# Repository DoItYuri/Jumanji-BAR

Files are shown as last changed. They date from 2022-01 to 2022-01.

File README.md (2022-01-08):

# Jumanji-BAR
шкафчик-бар, дверцы в стиле Джуманджи, с озвучкой (бой барабанов) и подсветкой

> [!WARNING]
> проект только начинается, и планируется завершить его к Маю 2022...

# Задумка
Сделать шкаф-бар (для алкоголя) стилизованного под Джуманджи.

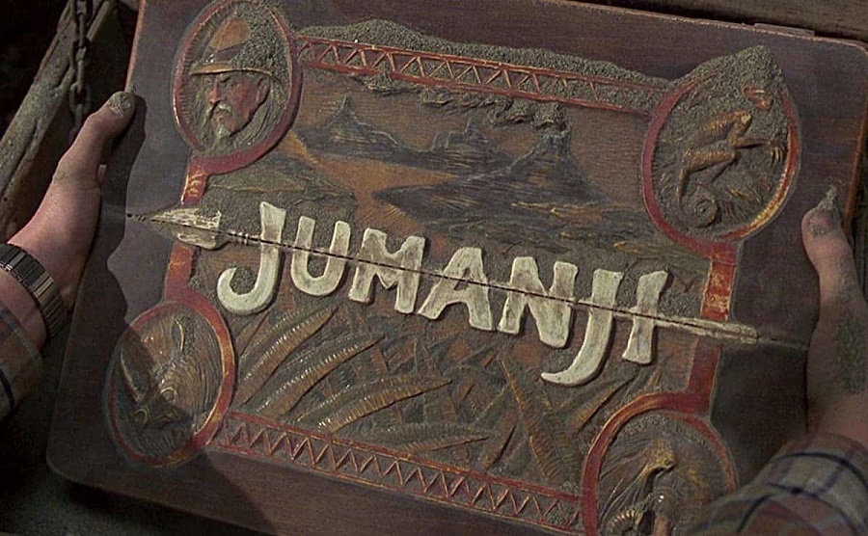
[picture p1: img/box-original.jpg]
original view


Кроме внешнего вида, будет музыкальное сопровождения, как в фильме.<br/>
При появлении рядом кого-либо, включается барабанный бой с постепенным нарастанием громкости<br/>
При приближении кого либо (к шкафу) - громкость и барабанный бой меняются до максимально громкого<br/>
При прикосновении к шкафчику (ручки-выемки сбоку) бой прекращается.<br/>
При открытии, включается подсветка в шкафчике (и можно включить саундтрек Jumanji)<br/>
При закрытии и отходе от шкафа, барабаны негромко и недолго снова играют.<br/>

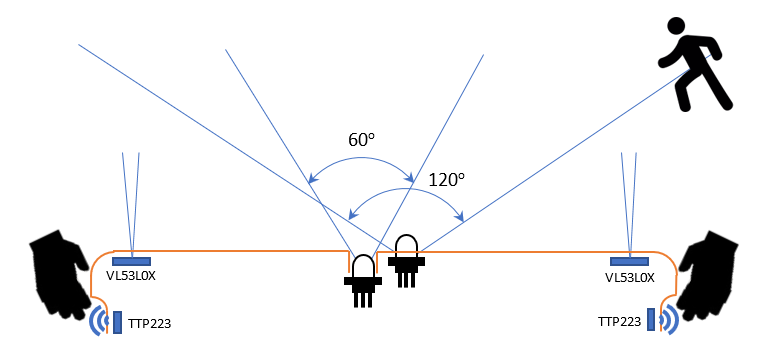
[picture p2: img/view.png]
view


# План действий
- барабанный бой можной найти в фильме, на 23-24 минутах, где дети поднимаются по лестнице и находят коробку.
Барабанный бой поделен на 4 части по интенсивности звучания:
    - далекий (который дети слышат его внизу)
    - средний (когда дети входят в комнату)
    - близкий (когда дети обнаружили коробку)
    - завершение (последние пара ударов в барабан для грациозного завершения, как в фильме)
- шкаф будет изготовлен из дерева, с фрезерованием на станке с ЧПУ. Нижняя дверца должна откидываться на 90 градусов и образовывать полку. Верхняя дверца должна синхронно подниматься кверху на 90 градусов. (Шкафчик будет больше и глубже чем коробка в фильме)
- музыкальная и интерактивная часть планируется с использованием Arduino Nano, прошивка которой и будет здесь представлена.

[3D model для фасада](https://www.thingiverse.com/thing:2410181)

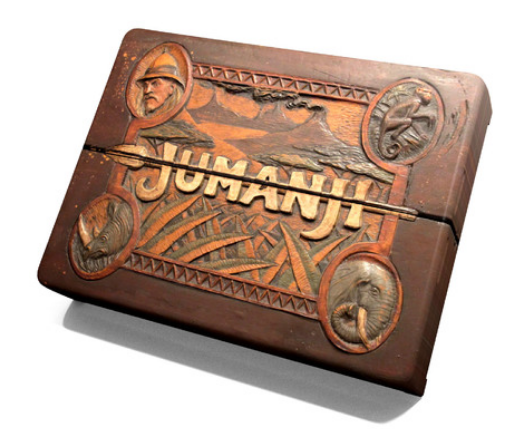
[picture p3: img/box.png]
3D model


# Компоненты
- Arduino Nano
- DFPlayer mini
- PIR (mini) sensor (x2)
- Distance sensor VL53L0X
- Touch sensor TTP223 (x2)
- Speaker 3W
- WS2812 strip (подсветка внутри, опционально)
- DC 5V 3A

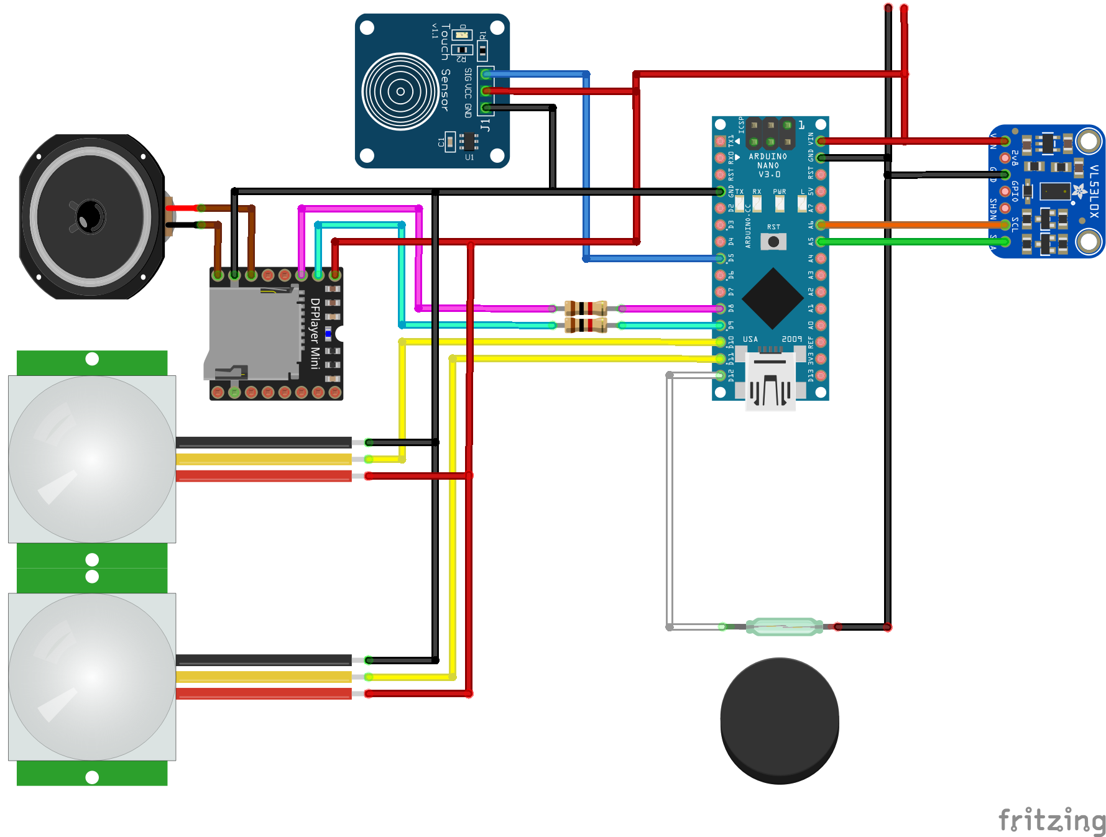
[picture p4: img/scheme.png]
scheme


при срабатывании ПИР1 датчика, включаем бой барабанов, с увеличением громкости от тихого до полного, <br/>
если сработал ПИР2 датчик (более направленного/ближнего радиуса действия) или при срабатывании дальномера VL57 включается бой барабанов 2 (средний)<br/>
при приближении до полуметра (дальномер VL53L0X), бой 3 (самый сильный)<br/>
при прикосновении к ТАЧ-сенсору, бой барабанов замолкает<br/>

# Потенциальные проблемы
|проблема|решение|
|---|---|
|ПИР-датчик определяет движение, а не присутствие|да и хрен с ним, если движение регистрируется долго или многократно, но никто не подходит, то отключать датчики ПИР, оставлять только дальномер. Если кто-то приблизился совсем близко или открыл ящик - включать ПИРы снова|
|Датчик расстояния VL53L0X узкий, а шкаф - широкий, как определять полное приближение с любой стороны?| два, три датчика (???)|
|Касание по всей поверхности деревянного ящика не сделать, а ручек нет|Ручки есть, углубления по бокам, ставить сенсоры касания туда|
|В ночное время барабаны могут мешать спать|Громкость регулировать<br>Ящик отключать<br>Датчик освещения или часы<br>Всё выше сказанное вместе|
|В зависимости от размещения шкафа, оба датчика PIR могут срабатывать одновременно при появлении человека|Нужна регулировка области видимости второго датчика, шторка или поворот (врезать в дверцу уже не вариант)|
|Недостаточно мощный звук при питании от 5в, а усилитель и динамики большего размера негде размещать и прятать||
|Круглый дисплей внутри коробки, с анимацияями и пр. - дорого и сложно|Линза, трафарет с текстом "джуманжи" и переливающаяся подсветка|

# Звуки
в папке mp3 лежат
- оригинальный фрагмент из фильма
- папка 01 - её следует скопировать на microSD, прямо как есть - папкой
> [!WARNING]
> Файлы mp3 удлинены и отредактированы наспех, для попробовать. Это временный вариант.

(ПРОДОЛЖЕНИЕ СЛЕДУЕТ)

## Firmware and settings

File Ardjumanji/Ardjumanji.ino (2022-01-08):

//Jumanji BAR v0.00

#include <Wire.h>
#include <VL53L0X.h>
#include "SoftwareSerial.h"
#include "DFRobotDFPlayerMini.h"

#define DEBUG
#define PIN_MP3_RX2       9
#define PIN_MP3_TX2       8
#define PIN_PIR_1         11
#define PIN_PIR_2         10
#define PIN_KEY1          2
#define PIN_DOOR          3

int playerState = 0;  //no sound
int playerVolume = 0; //no volume

#define LEVEL3_DISTANCE   700 //actual distance 100mm less
#define LEVEL1_DELAY      8000
#define LEVEL2_DELAY      4000
#define LEVEL3_DELAY      2000
#define TOUCH_DELAY       3000
#define VOLUME_OUT_DELAY  1000
#define VOLUME_IN_DELAY   500
#define VOLUME_MAX        30
#define VOLUME_MIN        16

SoftwareSerial mySoftwareSerial2(PIN_MP3_RX2, PIN_MP3_TX2); // RX, TX
DFRobotDFPlayerMini myDFPlayer2;

VL53L0X sensor;

void setup()
{
#ifdef DEBUG
  Serial.begin(9600);
#endif
  
  Wire.begin();
  mySoftwareSerial2.begin(9600);
  myDFPlayer2.begin(mySoftwareSerial2);

  sensor.init();
  sensor.setTimeout(500);
  // lower the return signal rate limit (default is 0.25 MCPS)
  sensor.setSignalRateLimit(0.1);
  // increase laser pulse periods (defaults are 14 and 10 PCLKs)
  sensor.setVcselPulsePeriod(VL53L0X::VcselPeriodPreRange, 18);
  sensor.setVcselPulsePeriod(VL53L0X::VcselPeriodFinalRange, 14);

#ifdef DEBUG
  if (!myDFPlayer2.begin(mySoftwareSerial2)) {  //Use softwareSerial to communicate with mp3.
    Serial.println(F("Unable to begin: 2"));
    Serial.println(F("1.Please recheck the connection!"));
    Serial.println(F("2.Please insert the SD card!"));
    //while(true);
  }
#endif
  pinMode(PIN_PIR_1, INPUT); 
  pinMode(PIN_PIR_2, INPUT); 
  pinMode(PIN_KEY1, INPUT_PULLUP); 
  pinMode(PIN_DOOR, INPUT_PULLUP); 

  myDFPlayer2.volume(0);
  
#ifdef DEBUG
  int num = myDFPlayer2.readFileCountsInFolder(1);
  Serial.print("files found: ");
  Serial.println(num);
  Serial.println("Setup has finished");
#endif
}

bool isBodyPresent(){
  static uint8_t oldVal=0;
  static unsigned long moment = 0;
  uint8_t val = digitalRead(PIN_PIR_1);
  if(oldVal != val){
#ifdef DEBUG
    Serial.print(F("PIR 1 val "));
    Serial.println(val);
#endif
    oldVal = val;
    if(val == LOW)moment = millis() + LEVEL1_DELAY;
  }
  return val == HIGH || (val == LOW && moment > millis());
}
bool isBodyNear(){
  static uint8_t oldVal=0;
  static unsigned long moment = 0;
  uint8_t val = digitalRead(PIN_PIR_2);
  if(oldVal != val){
#ifdef DEBUG
    Serial.print(F("PIR 2 val "));
    Serial.println(val);
#endif
    oldVal = val;
    if(val == LOW)moment = millis() + LEVEL2_DELAY;
  }
  return val == HIGH || (val == LOW && moment > millis());
}

bool isBodyCloser(int distance){
  static bool oldVal = false;
  static unsigned long moment = 0;
  bool val = false;
  int d = sensor.readRangeSingleMillimeters();
  if (sensor.timeoutOccurred() ) {
    val = oldVal;
  }
  else{
    val = (d - distance) < -100;
  }
  if(oldVal != val){
#ifdef DEBUG
    Serial.print(F("level 3 val "));
    Serial.println(val);
#endif
    oldVal = val;
    if(val == false)moment = millis() + LEVEL3_DELAY;
  }
  return val == true || (val == false && moment > millis());
}

bool isTouched(){
  static uint8_t oldVal=0;
  static unsigned long moment = 0;
  uint8_t val = digitalRead(PIN_KEY1);
  if(oldVal != val){
    oldVal = val;
    if(val == LOW)moment = millis() + TOUCH_DELAY;
#ifdef DEBUG
    Serial.print(F("touch val "));
    Serial.println(val);
#endif
  }
  return val == HIGH || (val == LOW && moment > millis());;
}

bool isDoorClosed(){
  static uint8_t oldVal=0;
  uint8_t val = digitalRead(PIN_DOOR);
  if(oldVal != val){
#ifdef DEBUG
    Serial.print(F("DOOR CLOSED "));
    Serial.println(val == HIGH);
#endif
    oldVal = val;
  }
  return val == HIGH;
}
void changeState(int newState){
  if(newState == playerState)return;
#ifdef DEBUG
  Serial.print(F("changeState "));
  Serial.print(playerState);
  Serial.print(F(" to "));
  Serial.println(newState);
#endif
  if(newState > playerState){
    playerState = newState;
    if(playerState > 1 || playerVolume == VOLUME_MIN){
      startPlaying(playerState);
    }
  }
  if(newState < playerState){
    playerState = newState;
    startPlaying(playerState);
  }
}
void startPlaying(int num){
  static unsigned long moment = 0;
  if(num > 0){
    if(playerState > 0){
      //need to wait for apropriate moment before change the track
      while((millis()-moment)%720 < 10);
    }
    myDFPlayer2.playFolder(1,num);
    moment = millis();
#ifdef DEBUG
    Serial.print(F("Start playing "));
    Serial.println(num);
#endif
  }
}
void volumeLoop(){
  static unsigned long moment = 0;
  if(playerState == 0 && playerVolume > VOLUME_MIN && moment < millis()){
    playerVolume-=2;
    if(playerVolume <= VOLUME_MIN){
      playerVolume = VOLUME_MIN;
      myDFPlayer2.stop();
#ifdef DEBUG
      Serial.println(F("STOP playing"));
#endif
    }
    else{
      myDFPlayer2.volume(playerVolume);
      moment = millis() + VOLUME_OUT_DELAY;
      #ifdef DEBUG
      Serial.print(F("Volume fade out "));
      Serial.println(playerVolume);
      #endif
    }
  }
  if(playerState == 1 && playerVolume < VOLUME_MAX && moment < millis()){
    playerVolume+=2;
    if(playerVolume > VOLUME_MAX)playerVolume=VOLUME_MAX;
    #ifdef DEBUG
    Serial.print(F("Volume fade in "));
    Serial.println(playerVolume);
    #endif
    myDFPlayer2.volume(playerVolume);
    moment = millis() + VOLUME_IN_DELAY;
  }
  if(playerState > 1 && playerVolume < VOLUME_MAX){
    playerVolume = VOLUME_MAX;
    #ifdef DEBUG
    Serial.print(F("Volume max "));
    Serial.println(playerVolume);
    #endif
    myDFPlayer2.volume(playerVolume);
  }
}
void loop(){
  volumeLoop();
  if(isDoorClosed())
  {
    if(isTouched()){
      changeState(4);
    }
    else{
      if(isBodyCloser(LEVEL3_DISTANCE)){
        changeState(3);
      }
      else{
        if(isBodyNear()){
          changeState(2);
        }
        else{
          if(isBodyPresent()){
            changeState(1);
          }
          else{
            changeState(0);
          }
        }
      }
    }
  }

  if (myDFPlayer2.available()) {
    printDetail(myDFPlayer2.readType(), myDFPlayer2.read()); //Print the detail message from DFPlayer to handle different errors and states.
  }
  delay(100);
}

void printDetail(uint8_t type, int value){
  switch (type) {
    case TimeOut:
      Serial.println(F("Time Out!"));
      break;
    case WrongStack:
      Serial.println(F("Stack Wrong!"));
      break;
    case DFPlayerCardInserted:
      Serial.println(F("Card Inserted!"));
      break;
    case DFPlayerCardRemoved:
      Serial.println(F("Card Removed!"));
      break;
    case DFPlayerCardOnline:
      Serial.println(F("Card Online!"));
      break;
    case DFPlayerUSBInserted:
      //Serial.println("USB Inserted!");
      break;
    case DFPlayerUSBRemoved:
      //Serial.println("USB Removed!");
      break;
    case DFPlayerPlayFinished:
      //Serial.print(F("Number:"));
      //Serial.print(value);
      //Serial.println(F(" Play Finished!"));

      break;
    case DFPlayerError:
      Serial.print(F("DFPlayerError:"));
      switch (value) {
        case Busy:
          Serial.println(F("Card not found"));
          break;
        case Sleeping:
          //Serial.println(F("Sleeping"));
          break;
        case SerialWrongStack:
          Serial.println(F("Get Wrong Stack"));
          break;
        case CheckSumNotMatch:
          Serial.println(F("Check Sum Not Match"));
          break;
        case FileIndexOut:
          //Serial.println(F("File Index Out of Bound"));
          break;
        case FileMismatch:
          Serial.println(F("Cannot Find File"));
          //errNoFile = 1;
          break;
        case Advertise:
          //Serial.println(F("In Advertise"));
          break;
        default:
          break;
      }
      break;
    default:
      break;
  }
}

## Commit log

2022-01-08 идея проекта
    [jumanji.fzz]
2022-01-08 mp3 с барабанами
